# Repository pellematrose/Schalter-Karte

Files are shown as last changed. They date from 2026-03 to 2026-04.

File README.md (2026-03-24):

# Schalter-Karte

Eine Schalter-Karte als Ersatz für Sicherungsautomaten in 24V-Systemen.

---

## 🔧 Gedachte Verwendung
Das Modul ist gedacht als **Schaltbare Sicherung für den Pluspfad** und ist damit Vergleichbar mit einem klassischen **Sicherungsautomaten**.

An die Schraubklemme **J1** wird **24V** angeschlossen. Die zweite Schraubposition kann zum durchverdrahten mit weiteren Modulen genutzt werden.  

Eine **Autosicherung** schützt die angeschlossene Last, die an **J2** angeschlossen wird.

Über den **Schiebeschalter** kann zwischen **Strompfad A und B** umgeschaltet werden:

- **Schalterstellung A**  
  → Verbraucher **A EIN**, **B AUS**

- **Schalterstellung B**  
  → Verbraucher **B EIN**, **A AUS**

Die Anschlüsse **A** und **B** an **J2** werden jeweils über den Schalter auf **24V** geschaltet.

Der angeschlossene Verbraucher erhält **GND extern**.

---

## 📏 Technische Daten

- Versorgungsspannung: 24V (+-20%)
- Laststrom: 4A (Schiebeschalter, Leiterbahnen)
- **PCB Maße:** 17,5 mm × 77 mm  
- Die Abmessungen orientieren sich an einem **Sicherungsautomaten**

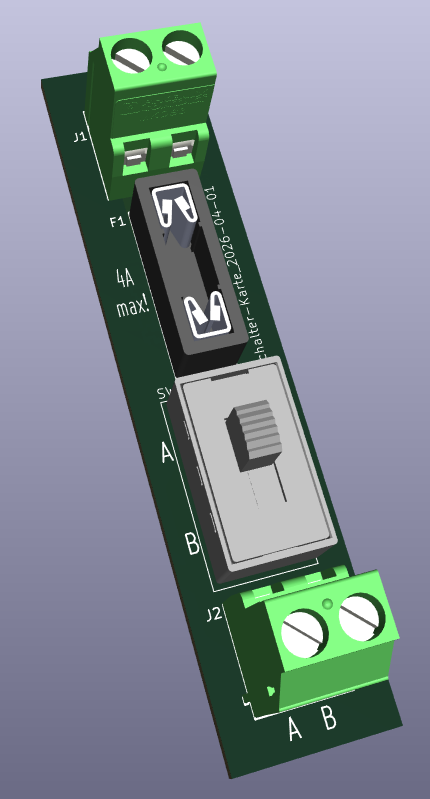
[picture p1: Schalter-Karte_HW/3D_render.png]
3D Render

---

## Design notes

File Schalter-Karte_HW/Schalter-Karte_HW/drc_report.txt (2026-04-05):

** Drc report for Schalter-Karte_HW.kicad_pcb **
** Created on 2026-04-01T14:25:28 **
** Report includes: Errors, Warnings **

** Found 0 DRC violations **

** Found 0 unconnected pads **

** Found 0 Footprint errors **

** Ignored checks **
    - Clearance violation
    - Footprint has no courtyard defined
    - Track endpoint not centered on via
    - Tuning profile track geometries
    - Footprint doesn't match symbol's footprint filters
    - PTH inside courtyard
    - NPTH inside courtyard
    - Footprint component type doesn't match footprint pads

** End of Report **

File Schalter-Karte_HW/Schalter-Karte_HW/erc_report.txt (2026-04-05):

ERC report (2026-04-01T14:25:25, Encoding UTF8)
Report includes: Errors, Warnings

***** Sheet /
[power_pin_not_driven]: Input Power pin not driven by any Output Power pins
    ; error
    @(111.76 mm, 67.31 mm): Symbol #PWR010 Pin 1 [Stromversorgung, Linie]
[power_pin_not_driven]: Input Power pin not driven by any Output Power pins
    ; error
    @(127.00 mm, 67.31 mm): Symbol #PWR011 Pin 1 [Stromversorgung, Linie]
[lib_symbol_mismatch]: Symbol "_PCB" stimmt nicht mit Kopie in Bibliothek "_PS_LIB" überein
    ; warning
    @(149.86 mm, 162.56 mm): Symbol PCB1 [_PCB]

 ** ERC messages: 3  Errors 2  Warnings 1

 ** Ignored checks:
    - Global label only appears once in the schematic
    - Four connection points are joined together
    - SPICE model issue
    - Assigned footprint doesn't match footprint filters

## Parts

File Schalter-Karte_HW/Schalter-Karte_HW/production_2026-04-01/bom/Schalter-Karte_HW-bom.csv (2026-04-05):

Reference | QUANTITY | Value | Footprint | LCSC | Digikey | Mouser
F1 | 1 | 3557-2 | _PS_LIB_CON:Fuse Holder Littelfuse ATOF 287 |  | 36-3557-2-ND
J1,J2 | 2 | MKDS_3-2_5.08 | _PS_LIB_CON:MKDS_3_2_508 |  | 277-1027-ND
SW1 | 1 | L102011MS02Q | _PS_LIB_MECH:L10101_Schiebeschalter |  | CKC5106-ND

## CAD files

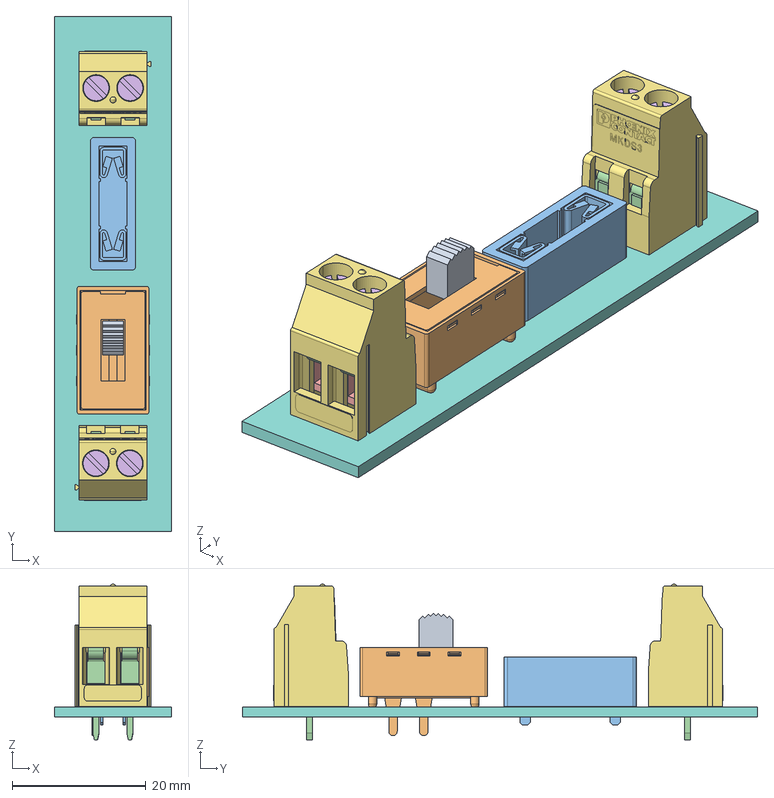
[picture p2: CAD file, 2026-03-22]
Schalter-Karte_HW/Schalter-Karte_HW/production_2026-03-22/step/Schalter-Karte_HW.step
17.5 x 77.0 x 23.3 mm
L101011MS02Q_PART1
Schalter-Karte_HW_PCB

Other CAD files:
Schalter-Karte_HW/Schalter-Karte_HW/production_2026-04-01/step/Schalter-Karte_HW.step

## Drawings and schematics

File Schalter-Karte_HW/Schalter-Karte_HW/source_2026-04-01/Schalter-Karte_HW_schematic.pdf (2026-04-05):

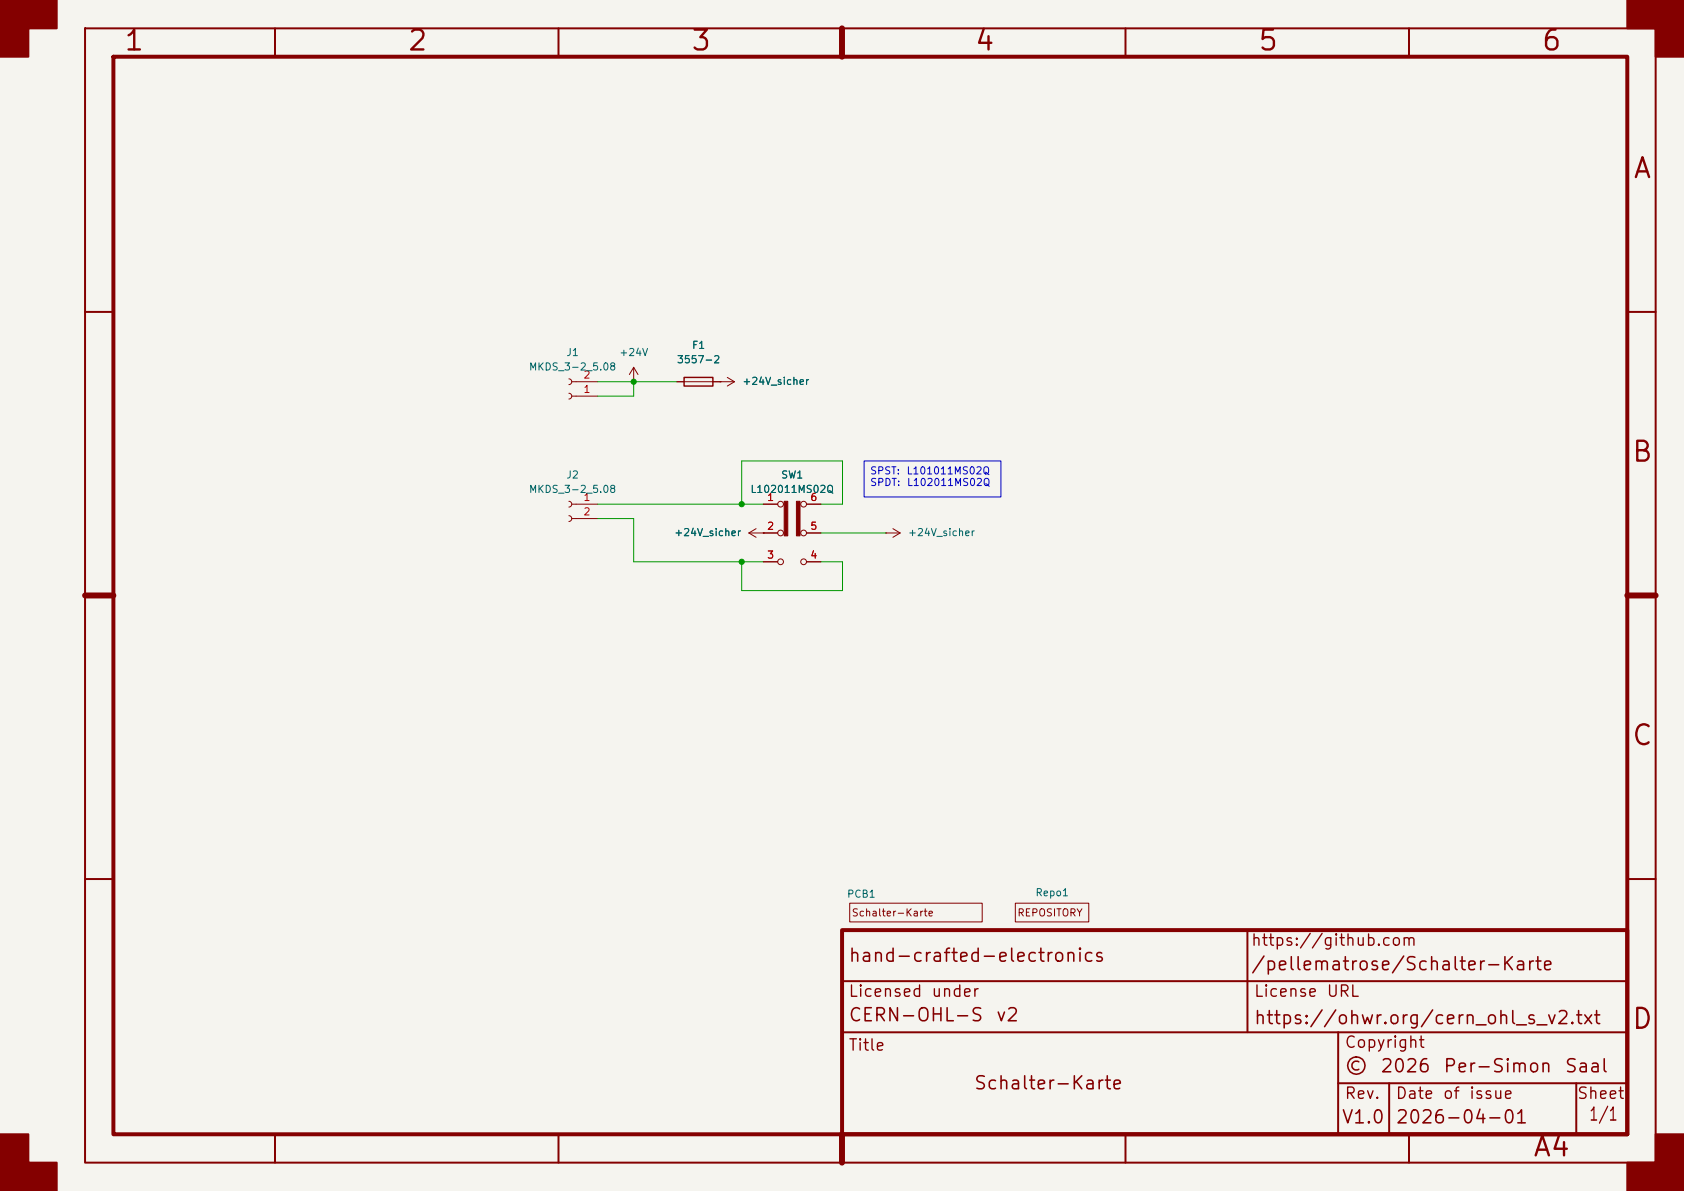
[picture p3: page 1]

hand-crafted-electronics | https://github.com/pellematrose/Schalter-Karte

Licensed under CERN-OHL-S v2 | License URL https://ohwr.org/cern_ohl_s_v2.txt

Title Schalter-Karte | Copyright © 2026 Per-Simon Saal

Rev. V1.0 | Date of issue 2026-04-01 | Sheet 1/1

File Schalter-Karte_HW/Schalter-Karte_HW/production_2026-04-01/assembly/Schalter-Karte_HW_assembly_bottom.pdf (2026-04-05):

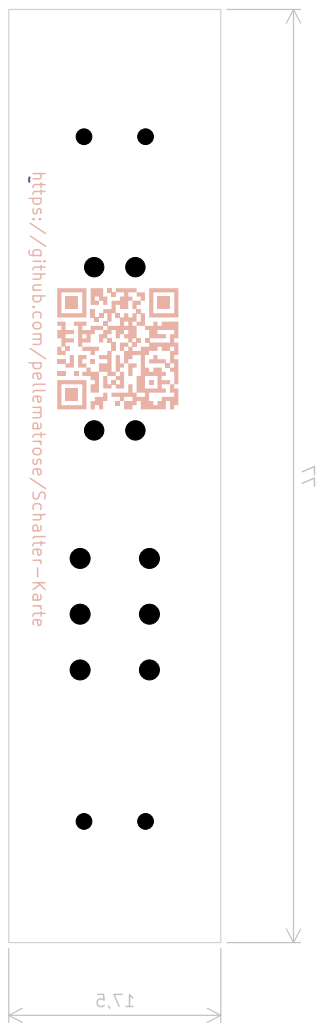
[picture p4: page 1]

hand-crafted-electronics | https://github.com/pellematrose/Schalter-Karte

Licensed under Licensed under CERN-OHL-S v2 | License URL https://ohwr.org/cern_ohl_s_v2.txt

Title Schalter-Karte | © 2026 Per-Simon Saal

Rev. V1.0 | Date of issue 2026-04-01 | Sheet 1/1

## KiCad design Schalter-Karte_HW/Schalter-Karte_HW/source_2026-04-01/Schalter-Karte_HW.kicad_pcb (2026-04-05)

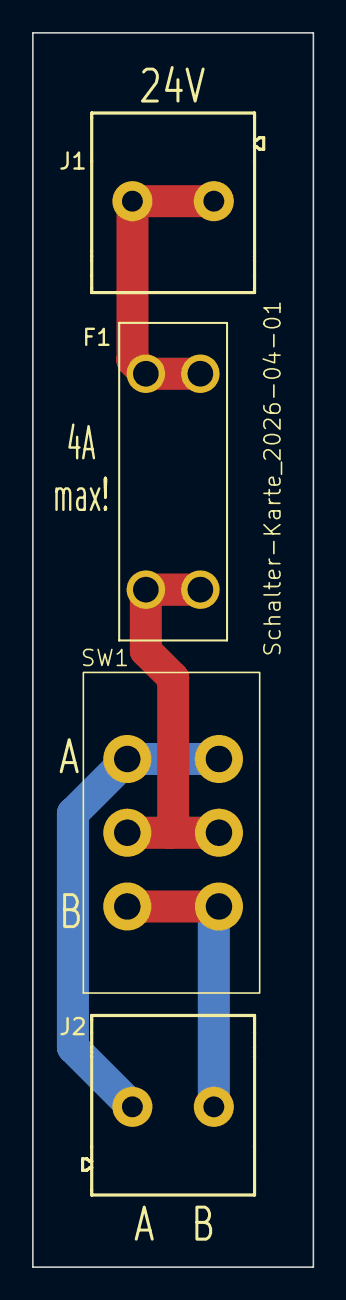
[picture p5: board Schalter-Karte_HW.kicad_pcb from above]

Board: 2 copper layers, 17.5 x 77.0 mm, 6 parts (1 on the bottom side), 4 nets.

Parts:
F1: 3557-2; Fuse Holder Littelfuse ATOF 287
J1, J2: MKDS_3-2_5.08; MKDS_3_2_508
PCB1: _PCB
Repo1: _Repository
SW1: L102011MS02Q; L10101_Schiebeschalter

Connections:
+24V: F1.1, J1.1, J1.2
+24V_sicher: F1.2, SW1.2 (B), SW1.5 (B)
unnamed: J2.1, SW1.1 (A), SW1.6 (C)
unnamed: J2.2, SW1.3 (C), SW1.4 (A)

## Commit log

2026-03-20 assembly drawings added
    [Schalter-Karte_HW-B_Courtyard.gbr, Schalter-Karte_HW-B_Cu.gbl, Schalter-Karte_HW-B_Fab.gbr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]
2026-03-22 gnd entfernt
    [Schalter-Karte_HW-B_Courtyard.gbr, Schalter-Karte_HW-B_Cu.gbl, Schalter-Karte_HW-B_Fab.gbr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]
2026-03-23 added geber zip file
    [Schalter-Karte_HW-B_Courtyard.gbr, Schalter-Karte_HW-B_Cu.gbl, Schalter-Karte_HW-B_Fab.gbr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]
2026-03-23 schalter typ angepasst
    [Schalter-Karte_HW-B_Cu.gbl, Schalter-Karte_HW-B_Mask.gbs, Schalter-Karte_HW-B_Paste.gbp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]
2026-04-05 final version
    [1711725_06_00_MKDS-3-2-5-08_3D.stp, 3557-2.step, L101011MS02Q_schiebeschalter.stp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]
